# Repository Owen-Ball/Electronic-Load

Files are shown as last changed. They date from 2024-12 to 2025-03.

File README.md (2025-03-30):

# Overview
 A DIY electronic load capable of 
* CC, CR, CP, Battery (BT) Modes
* 30V, 50mA-7.5A, 120W
* 0-12V @ 3mV resolution, 0-40V @ 10mV resolution
* 0-1A @ 300uA resolution, 0-10A @ 2.5mA resolution

The design uses a custom PCB featuring an ESP32S3 Feather microcontroller. 4 power FETs dissipate the power via a CPU heatsink and current is measured using a bank of power resistors. With proper calibration, measurements/setpoints are within 1% across the entire operational range. 

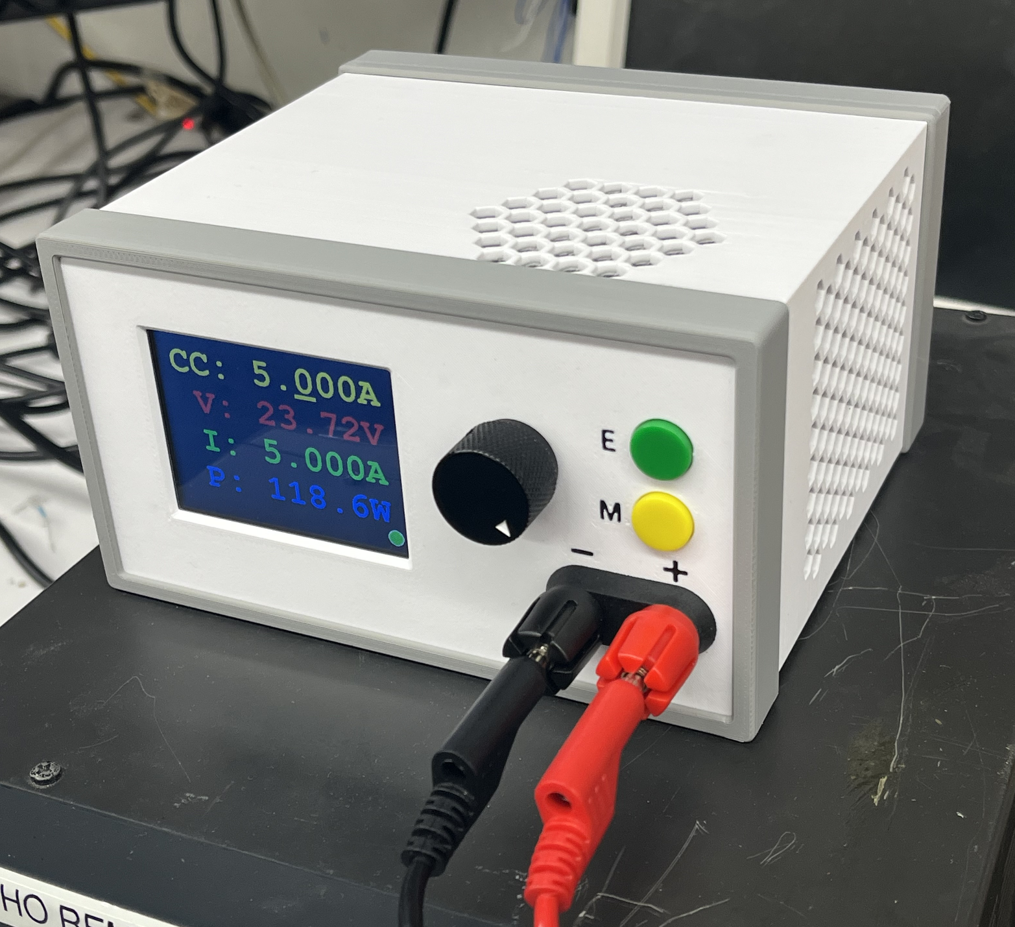
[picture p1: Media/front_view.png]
Front View

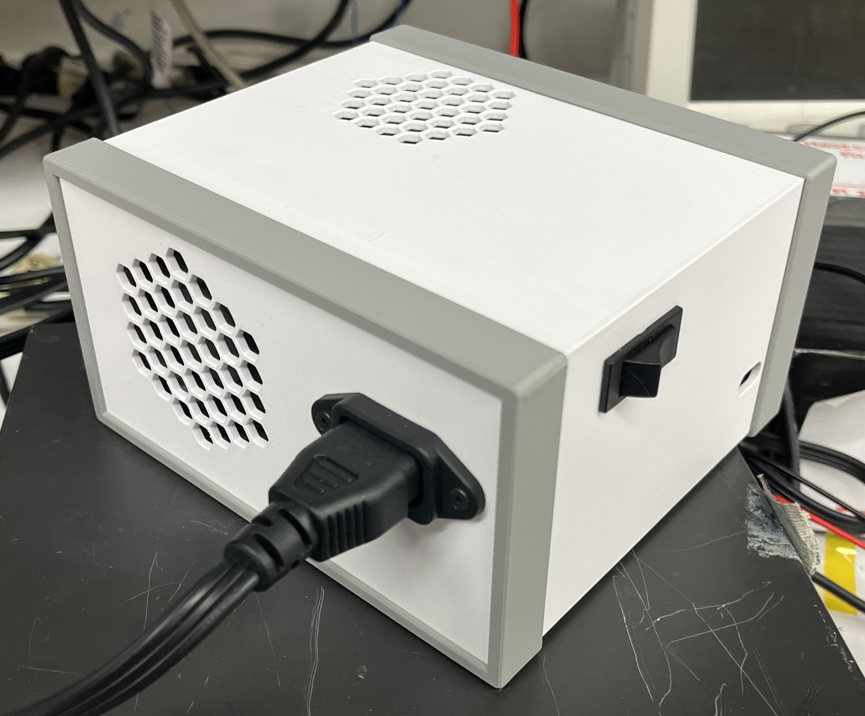
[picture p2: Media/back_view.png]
Back View


# To Do Feature List
* Check that the FET that burned is properly secured to heatsink
* CV mode? Not really sure for what application though

# Device Usage
This section provides a brief overview of device operation, including
* An overview of the UI elements
* Using the UI to operate the device
* Some potential pitfalls and things to look out for using the device
* Proper power connections and USB-C connections
## UI Overview
There are 5 "screens" on the UI, corresponding to the 4 operating modes of the device and a calibration screen. These are cycled through with the "mode" (M) button. The current mode is indicated in the top left. On each screen, the output can be enabled with the "enable" (E) button.

On each screen, the top-most value is the setpoint for the mode. This value is changed via the encoder. The 3 values below this are the measured values, which consist of the voltage, current, and either the power or discharged mAh in the case of battery mode. The temperature is also displayed at the bottom, along with any error messages. The output state is indicated by a red (off) or green (on) circle in the bottom right.

## Firmware Operation
On each screen, the rotary encoder can be used to change the setpoint within the system bounds. The place value being edited can be changed by clicking the encoder to cycle through place values, or by pressing down the encoder and turning it.

Once on the desired mode and with the correct setpoint, the enable button can be used to toggle the system output. The output indicator will turn green. If the output turns off unexpectedly, an error/warning message should be displayed indicating the reason, with most of these going away next time the enable button is pressed.

All modes operate in general by very roughly setting a current, maybe with 10-25% accuracy. The actual current is monitored and used to adjust the setpoint. This is done with an integral controller, which requires some sanity checking to ensure system safety. If there is no source connected (or it is underpowered), the system will detect this and shut off the output. More specifically, if the set current and measured current are not within a certain tolerance of each other for a set amount of time, the output is disabled.

Other reasons for system shutoff are voltage or temperature limits being exceeded. In CR or CP modes, since the current is automatically calculated the output will be shut off if the system tries to set the current or power above the system limit.

In rare circumstances the system can oscillate. This will occur in the presence of a slow responding source in series (ie an incandescent bulb) or through interactions with the feedback system of a power supply. There is no protection against this, so turn the system off if observed.

## Hardware Operation
While the system has some reverse polarity protection, it is highly recommended that this is not relied on. As such, make sure to connect the higher potential of the source to the +/red terminal and the lower to the -/black terminal. While the system should draw no current while powered off, I recommend having the system powered before connecting a source.

When connecting to the Feather using a USB-C cable, a cable with the 5V line cut is recommended. The system has diodes on the 5V lines so there are no shorting risks, but for some reason the system measurements differ by around 1% depending on whether the system receives USB power or not. Thus for calibration using the serial monitor, a cable with no power is essential. 

The system can be put into bootloader mode by pressing down the encoder while turning on the system (assuming you bridge the encoder pin and bootloader testpad on the feather together).

Additionally, please use caution when operating the device, as mains 120V power is used. There are potential areas of risk, including power supply failure and improper crimping for the live wires.

# Hardware

## Microcontroller

The microcontroller used is the ESP32S3 feather. This was done with the intention of adding WiFi support to the device for the monitoring and setting of parameters. However, the ESP32S3 has issues using both the ADC and WiFi at the same time, so this feature is on hold. Additionally, I did not have any significant use cases for the WiFi anyways. If not implementing WiFi functionality, the ESP32 is a poor choice due to the extremely non-linear ADCs that mandate extensive calibration.

## Power Components:
The bulk of the power is burned using 4 [IRFB7545PBF](https://www.digikey.com/en/products/detail/infineon-technologies/IRFB7545PBF/4772483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) NCH MOSFETs (TO-220). The FETs are mounted to a [CPU heatsink](https://www.amazon.com/dp/B00006B8EX?ref=ppx_yo2ov_dt_b_fed_asin_title&th=1) to thermally couple them and provide power dissipation. Current measurements are done using the voltage across banks of [RSMF2JT4R70](https://www.digikey.com/en/products/detail/stackpole-electronics-inc/RSMF2JT4R70/2021732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) 4.7 Ohm resistors. Each FET is in series with a bank of 4 of these resistors in parallel. The resistors are cooled via a fan mounted to the system case.

A 10A fuse is placed in series with the + input to the system. Some degree of reverse polarity protection is present in the form of a reverse biased diode across the input ports after the fuse. This ideally will limit reverse voltages to less than 1V but has not been tested.

## Sensing
All sensing is done via the ADCs on the ESP32S3. Accurary could be improved by purchasing more accurate standalone ICs for voltage and current measurements however. 

Voltage sensing has two ranges, 0-12V and 0-<span style="color:red"> 40V (need to check)</span>. Thus for a 12-bit ADC, resolution is around 3mV/step and 10mV/step. Both sensors operate using a simple voltage divider to divide down the max voltage to the maximum ADC input of ~3.2V. 7.5V zener diodes are used to clamp the voltage input to the ADCs to ~3.75V. 7.5V zeners are used since lower voltage zeners feature a less sharp turn on that would increase leakage and worsen the voltage clamping. One note is the pin used for the high voltage range on the ESP32S3 feather has an SMD LED attached to it (not sure why they put the on-board LED on an analog in pin...). For high voltage inputs, this drives the LED, which is not ideal and causes non-linearity in the measurement that needs to be compensated for. The LED could of course be removed, but I did not do this.

Current sensing is done with two ranges as well, although there are some major design oversights. The original intention was to have two operating modes, one where all 4 FETs were running and one were only a single one was active. This would enable higher precision for low current measurements. Thus 3 of the 4 FETs are controlled by 1 DAC and the final one is controlled by a separate DAC. 

The high sensitivity current sensor amplies the voltage across the power resistors by a factor of 10. Thus for 16 shunt resistors, this range maxes out around 1.1A. The design oversight is that this sensor is only hooked up to the independently controlled FET path, so in high current mode, this sensor is not truly measuring the current, it is "guessing" based on a measurement of 1/4 of the current.

The low sensitivity (higher range) current sensor uses resistors to average the voltages across the 4 shunts. This means it works properly in high current mode, but not in low, since this setup will not work when only the one FET is active. This mode peaks at around <span style="color:red"> 10A (need to check)</span>.

As a summary of the design oversights, the only fully functioning current sensing modes would be high current mode + low sensitivity sensor and low current mode, high sensitivity sensor. After discovering this issue, I cut support for low current mode entirely since I currently do not have a use case for the latter mode (would be 0-250mA), although this may be added in the future. I did decide to use the high sensitivity current sensor is used in high current mode despite only directly measuring 1/4 of the current.

# Firmware Details
More details regarding the firmware implementation can be found in the firmware-specific readme
[here](./Firmware/Firmware_ReadMe.md)

This includes:
* Error codes
* Feedback loops
* System FSM
* Calibration
* Setup

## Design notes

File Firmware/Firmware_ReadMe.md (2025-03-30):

# Error/Warning Codes
The system features a handful of warnings and errors that will be displayed on the screen. These are as follows:
* No message (NO_ERROR): No error present
* "I Sense Fail" (C_SENSE_ERROR): Discrepancy between low and high current sensors. Disables device, cannot be overwritten
* "Over Current" (OVER_C_ERROR): Current went over system limit
* "Over Voltage" (OVER_V_ERROR): Voltage went over system limit
* "Over Power" (OVER_P_ERROR): Power went over system limit
* "Over Temp" (OVER_T_ERROR): Heatsink temp went over system limit
* "I_Set!=I_Meas" (MISMATCH_ERROR): Set current is not being achieved within required margin of error

When triggered, a warning/error will turn off the output. Of these, all but C_SENSE_ERROR can be reset by simply re-enabling the output. 
C_SENSE_ERROR could indicate a failure of one of the power MOSFETs and can only be disabled via a power cycle. You should proceed with 
caution by testing the device at ~1A using a current limited supply.

# Library & Board Version Info
* Espressif Systems esp32: v2.0.14
    * Board: Adafruit Feather ESP32-S3 2MB PSRAM
    * Add https://raw.githubusercontent.com/espressif/arduino-esp32/gh-pages/package_esp32_index.json in _Additional Boards Manager_
* Adafruit BusIO: v1.16.2
* Adafruit_MCP4725: v2.0.2
* ESP32_FastPWM: v1.1.0
* ESP32Encoder: v0.11.6
* [FlickerFreePrint](https://github.com/KrisKasprzak/FlickerFreePrint) 
* TFT_eSPI: v2.5.43
    * Need to overwrite _Arduino\libraries\TFT_eSPI\User_Setup.h_ with the following: [User_Setup.h](User_Setup.h)

# Modes of Operation
All modes operate around setting a current on the device. Depending on the mode, this may be a constant current or it can be a function of voltage.

## Constant Current
Constant current mode directly sets a current output and attempts to keep it stable. 
The DACs in the device are only loosely calibrated, so when CC mode is started, 
the DACs are set roughly to the required voltage. The actual current is monitored 
and an integral controller is used to update the set DAC value until the measured 
current matches the user setpoint. This allows the device to maintain a constant 
current no matter what the applied voltage, temperature of FETs, etc is. Sanity 
checks must be performed to ensure the DAC setpoint and the measured current are
within some tolerance of each other to prevent runaway of the integral controller.

## Constant Power
Under the hood, constant power method uses the feedback loop from constant current mode. 
The only change is that in constant power mode, the target current value is calculated by
dividing the set power by the measured voltage. Because the device does not have sense wires,
the voltage drops of wires and connectors will impact the measured voltage. The result of this is
that slightly more power will be drawn from the connected supply than measured by the device.

## Constant Resistance
This mode also uses constant current mode, but the target current is set to the measured voltage divided
by the set resistance. Due to wire and connector drops, the actual current drawn will be slightly
lower than if the supply was connected to some ideal resistor of the set value.

## Battery Discharge Mode
In battery discharging mode, the device starts by pulling 5A from the connected supply. This
is achieved using the same constant current feedback loop as all other modes.
The measured voltage is compared to the user set end voltage. If the voltage drops below the end voltage
(some battery and E-load internal resistance is accounted for), the current setpoint will be 
dropped by a set value (currently 0.05A). This will occur until a minimum current is reached, at
which point the device will turn off. The battery voltage should now be quite close to the
set end voltage.

In battery discharge mode, the power reading is replaced by a mAh reading that indicates the total
number of mAh consumed from the battery. This value will be cleared when the mode is changed,
but will not change when you toggle the output on and off. When turned off and back on, the
current will reset to 5A

## Calibration Mode
This mode is used to account for resistive drops in the Eload and wires. This mode will set the current to 1A 
when the output is enabled. The resistance value shown can be changed until the voltage measured by the Eload 
matches with the voltage measured at the desired location with a kelvin connected voltmeter. The resistance value
set in this mode will be used in all other modes to update the measured voltage in accordance with the measured current.

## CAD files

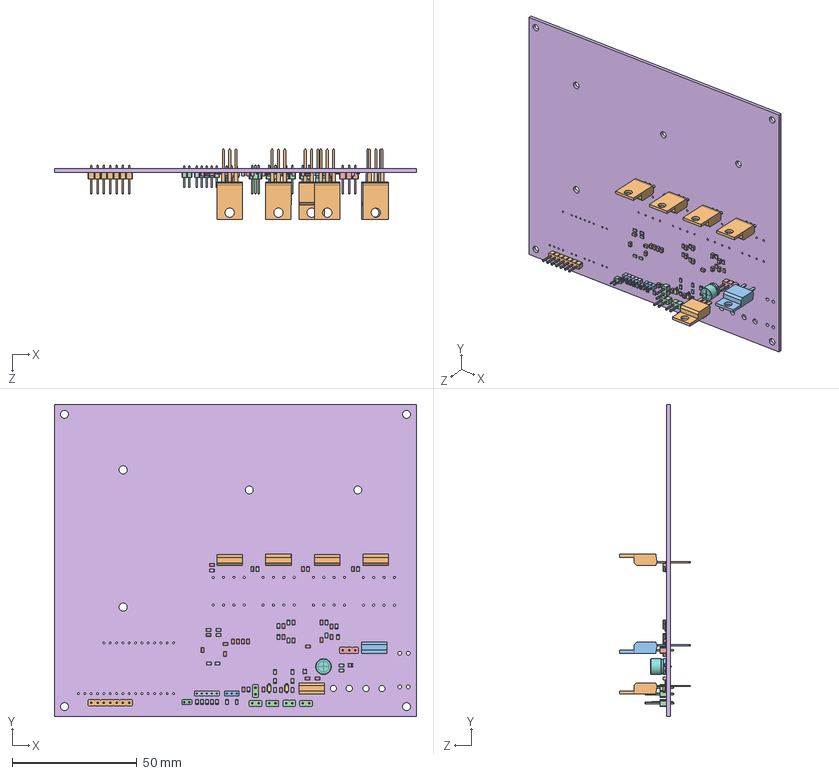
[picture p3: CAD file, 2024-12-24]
CAD/Board/Board.SLDASM
145.0 x 125.0 x 28.5 mm
Main PCB

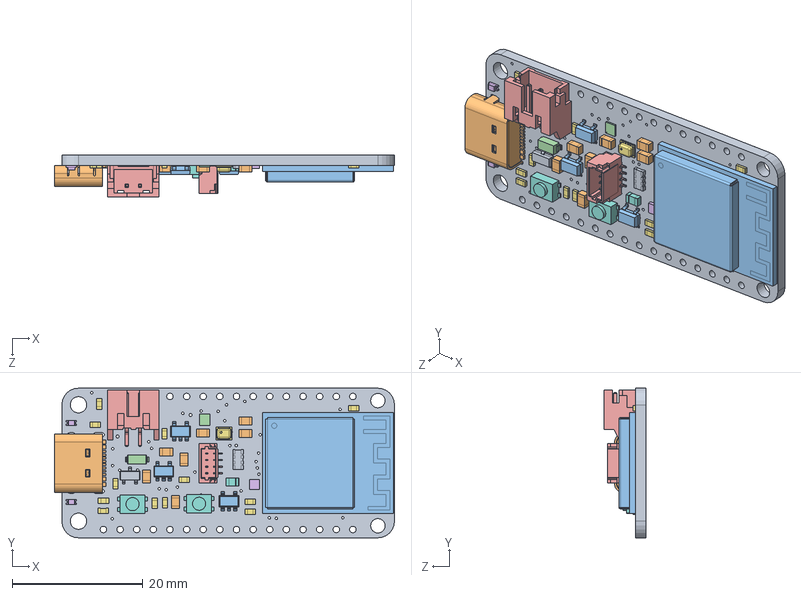
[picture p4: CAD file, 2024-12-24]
CAD/ESP32S3/5303 Feather ESP32-S3.SLDASM
51.9 x 22.9 x 6.37 mm
Board
10uF x 7
AP2112_RT9080-3.3 x 3
MBR540
JSTPH
RED x 2
1uF x 12
KMR2 x 2
DMG3415U
USB C
ESP32-S2-MODULE_MINI
LC709203F_MH
JST SH
WS2812B_SK6805_1515
BME280
10uF_1
10K

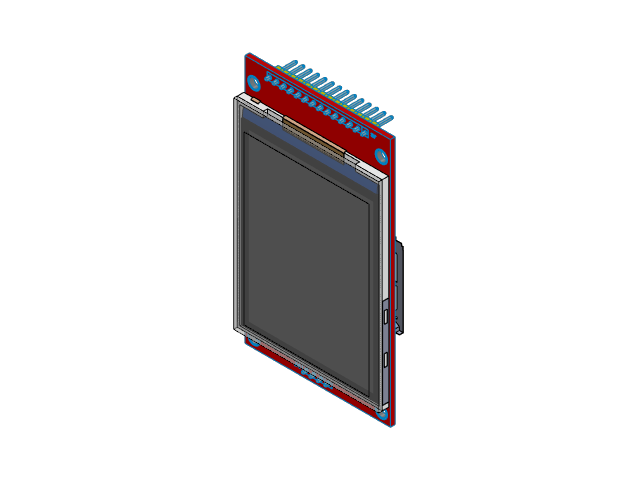
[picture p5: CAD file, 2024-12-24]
CAD/Screen/2.8 TFT Module.SLDASM
2.8 LCD TFT Module - Without Glass
0603 Resistor
0603 Capacitor x 2
SOT23-3 x 2
2.8in TFT(Without Glass)- Tucked Cable
front_glass

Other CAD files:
CAD/Board/Main PCB.SLDPRT
CAD/Board/TO-220-2_Vertical.SLDASM
CAD/Main PCB.SLDPRT
CAD/Board/PinHeader_1x02_P2.00mm_Vertical.SLDASM
CAD/Board/D_SOD-123.SLDASM
CAD/Board/D_0805_2012Metric.SLDASM
CAD/Board/TO-220-3_Vertical.SLDASM
CAD/Board/PinHeader_1x07_P2.54mm_Vertical.SLDASM
CAD/Board/R_0805_2012Metric.SLDASM
CAD/Board/PinHeader_1x03_P2.00mm_Vertical.SLDASM
CAD/Board/PinHeader_1x03_P2.54mm_Vertical.SLDASM
CAD/Board/PinHeader_1x02_P2.54mm_Vertical.SLDASM
CAD/Board/CP_Radial_D6.3mm_P2.50mm.SLDASM
CAD/Board/PinHeader_1x05_P2.00mm_Vertical.SLDASM
CAD/ESP32-S2-MODULE_MINI.SLDPRT
CAD/0603 Capacitor.SLDPRT
CAD/0603 Resistor.SLDPRT
CAD/10K.SLDPRT
CAD/10uF.SLDPRT
CAD/10uF_1.SLDPRT
CAD/1uF.SLDPRT
CAD/2.8 LCD TFT Module - Without Glass.SLDPRT
CAD/2.8in TFT(Without Glass)- Tucked Cable.SLDPRT
CAD/5035000993.SLDPRT
CAD/AP2112_RT9080-3.3.SLDPRT
CAD/BME280.SLDPRT
CAD/BindingPost.SLDPRT
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

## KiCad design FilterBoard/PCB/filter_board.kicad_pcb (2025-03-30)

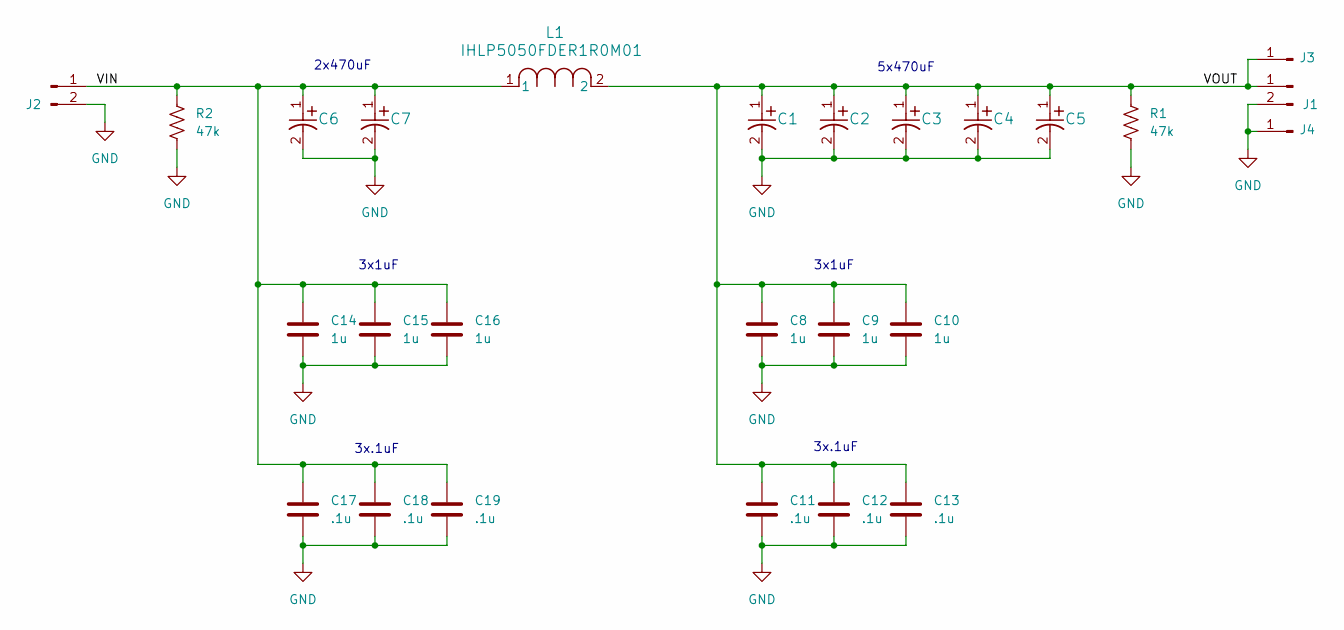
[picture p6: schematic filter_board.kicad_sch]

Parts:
C1, C2, C3, C4, C5, C6, C7: EMHB630ARA471MMH0S
C8, C9, C10, C14, C15, C16: 1u; C_0805_2012Metric
C11, C12, C13, C17, C18, C19: .1u; C_0805_2012Metric
J1: Banana_Terminals
J2: Banana Terminals; Banana_Terminals
J3, J4: Conn_01x01_Pin; Wire_Pad
L1: IHLP5050FDER1R0M01; IND_IHLP-5050FD-01_VIS
R1, R2: 47k; R_0805_2012Metric

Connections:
/VIN: C6.1, C7.1, C14.1, C15.1, C16.1, C17.1, C18.1, C19.1, J2.1, L1.1, R2.1
/VOUT: C1.1, C2.1, C3.1, C4.1, C5.1, C8.1, C9.1, C10.1, C11.1, C12.1, C13.1, J1.1, J3.1, L1.2, R1.1
GND: C1.2, C2.2, C3.2, C4.2, C5.2, C6.2, C7.2, C8.2, C9.2, C10.2, C11.2, C12.2, C13.2, C14.2, C15.2, C16.2, C17.2, C18.2, C19.2, J1.2, J2.2, J4.1, R1.2, R2.2

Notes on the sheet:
2x470uF
3x.1uF
5x470uF
3x1uF

Board: 2 copper layers, 26 parts (0 on the bottom side), 3 nets, no tracks yet.

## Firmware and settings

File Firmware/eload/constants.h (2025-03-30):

#ifndef _CONSTANTS_
#define _CONSTANTS_

enum OUT_STATE {OUT_ON, OUT_OFF};
enum MODE {CC, CV, CP, CR, BAT, R_CAL};
enum CURRENT_LIMIT {CURR_LOW, CURR_HIGH};

//NO_ERROR: No error present. Set to this value when output enabled
//C_SENSE_ERROR: Discrepancy between low and high current sensors
//               Disables device, cannot be overwritten
//OVER_C_ERROR: Current went over system limit
//OVER_V_ERROR: Voltage went over system limit
//OVER_P_ERROR: Power went over system limit
//OVER_T_ERROR: Heatsink temp went over system limit
//MISMATCH_ERROR: Set current is not being achieved within required margin of error
enum ERROR_CODE {NO_ERROR, C_SENSE_ERROR, OVER_C_ERROR, OVER_V_ERROR, OVER_P_ERROR, OVER_T_ERROR, MISMATCH_ERROR};

//Setpoint Bounds
#define MAX_CURRENT_LOW_SET   1.50
#define MAX_CURRENT_HIGH_SET  7.50
#define MAX_VOLTAGE_SET       30.00
#define MIN_RESISTANCE_SET    0.50
#define MAX_RESISTANCE_SET    500.00
#define MAX_POWER_SET         120.00
#define MAX_CAL_SET           0.5

//Configure default setpoint values
#define DEFAULT_CC            1.00
#define DEFAULT_CV            5.00
#define DEFAULT_CP            10.00
#define DEFAULT_CR            10.00
#define DEFAULT_BAT           15.30
#define DEFAULT_RCAL          0.0

//The current that will be injected during calibration
#define I_CAL                 1.0

//System Limits
#define CURRENT_LOW_LIMIT     2.00
#define CURRENT_HIGH_LIMIT    7.7
#define VOLTAGE_LIMIT         33.00
#define POWER_LIMIT           125.0
#define TEMP_LIMIT            60.0



//Pins
#define FAN_PIN               11
#define PWM_RES               10
#define PWM_FREQ              20000
#define PWM_CHANNEL           0

#define ENABLE_BUTTON_PIN     38
#define CURRENT_BUTTON_PIN    14
#define MODE_BUTTON_PIN       39
#define ENCODER_BUTTON_PIN    16
#define ENCODER_A             3
#define ENCODER_B             4

#define VSENSE_LARGE          13
#define VSENSE_SMALL          12
#define CURRSENSE_LARGE       6
#define CURRSENSE_SMALL       5
#define THERMISTOR_PIN        8

#define DAC_SDA               10
#define DAC_SCL               9

//debounce time for all I/O buttons
#define DEBOUNCE_TIME_MS      50
//Takes N digital readings of each button, all must agree for output state to toggle
//This was implemented to solve an infrequent issue where the current limit would randomly update due to
//digitalRead of the button returning the wrong value
#define BUTTON_AVG_COUNT      10




//Below this voltage the low voltage sensor will be used
#define V_THRESH_LOW          11.0
//Above this voltage the high voltage sensor will be used
//Between them the previous sensor is used
#define V_THRESH_HIGH         12.0

//On the high current setting, below this current the low current sensor is used
#define C_THRESH_LOW          0.7
//On the high current setting, above this current, the high current sensor is used
#define C_THRESH_HIGH         0.8

//defines how long the current can be outside of 25% of the setpoint before being cut (ms)
#define OUT_KILL_TIME_LIMIT   500




//Vertical spacing between lines
#define LETTER_HEIGHT         50
//defines the x coordinate of the left of the numbers
#define LETTER_X              45
//defines the y coordiante of the top of the numbers
#define LETTER_Y              50

//time in ms between screen updates
#define SCREEN_REFRESH        75

#define DEBUG_LEN             21



//Defines the number of samples taken for analog input readings
#define SAMPLE_COUNT          200
//If the large current reads this much above the small current sensor, turn off the device
#define SAFETY_OFFSET         0.25
//Triggering of the safety shutoff requires this many invalid readings in a row
#define SAFETY_COUNT          3
//sets the IIR filter used on values before displaying them. 
//Only impacts the displayed values, not the values used in control loops and such
//0 = no filter, -> 1 = high filtering
#define MEASUREMENT_FILTER    .75
//Will skip filtering and directly set the measured value if the filtered value has a percent error
//greater than the below value. Makes output responsive to large steps
#define FILTER_THRESHOLD      .02




//sets the gain of the integral controller for current setpoint
//1 or above likely to cause oscillations
#define CURRENT_SET_GAIN      .8

//Filters how fast the set current can change for CR, CP, CV
#define CURRENT_SET_FILTER    .75



//time in ms between current decreases in battery discharge mode
#define BAT_UPDATE_TIME       100
//Value of current steps in battery discharge mode
#define BAT_CURRENT_STEP      .05
//Speeds up discharging process by allowing measured voltage to drop below desired end voltage when
//at high currents, since resistive losses result in voltage drop
//Must be below actual resistance to avoid over discharging
#define BAT_RESISTANCE        0.02
//Cut off current for battery discharging
#define BAT_END_CURRENT       0.2

#endif // _CONSTANTS_

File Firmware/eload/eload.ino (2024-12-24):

#include "Arduino.h"
#include <cstdint>
#include "drawing.h"
#include "IO.h"
#include "helpers.h"
#include "FSM.h"
#include "debug_utils.h"

long prevtime;

void setup() {
  
  pinMode(VSENSE_LARGE, INPUT);
  pinMode(VSENSE_SMALL, INPUT);
  pinMode(CURRSENSE_LARGE, INPUT);
  pinMode(CURRSENSE_SMALL, INPUT);
  pinMode(THERMISTOR_PIN, INPUT);
  
  encoder.attachFullQuad (ENCODER_A, ENCODER_B);
  
  Wire.begin(DAC_SDA, DAC_SCL);
  dac_low.begin(0x60, &Wire);
  dac_high.begin(0x61, &Wire);
  dac_low.setVoltage(0, false);
  dac_high.setVoltage(0, false);

  Serial.begin(115200);
  
  tft.init();
  tft.setRotation(1);
  tft.fillScreen(TFT_BLACK);
  tft.setTextSize(1);
  tft.setTextColor(TFT_YELLOW, TFT_BLACK);
  tft.setFreeFont(&FreeMonoBold24pt7b);

  encoder_button.begin();
  enable_button.begin();
  mode_button.begin();
  current_button.begin();
  coolingFan = new ESP32_FAST_PWM(FAN_PIN, PWM_FREQ, 0.0f, PWM_CHANNEL, PWM_RES);

  initSystem();

  prevtime = millis();
}

void loop() {
  
  drawAll();
  updateSystem();
  
  DEBUG_PRINTLN(millis() - prevtime);
  DEBUG_PRINTLN("Error: " + String(ERRORS));
  
  prevtime = millis();

  //float small = analogReadAverage(CURRSENSE_SMALL, 1000);
  //float large = analogReadAverage(CURRSENSE_LARGE, 1000);
  //DEBUG_PRINTLN(String(small, 2) + " " + String(large, 2));
  //if (mode_button.pressed()) i+=100;
  //dac_low.setVoltage(i, false);
  //dac_high.setVoltage(0, false);
}

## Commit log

2024-06-16 Renamed main arduino file
2024-06-17 Added CR and CP functionality
    Added constant resistance and power modes. Need to fix the setpoint being kept constant between modes and need to add protection to shut the output off if the desired setpoint cannot be achieved.
    [IO.cpp, constants.h, eload.ino]
2024-06-28 Sped up main loop, added filtering to display measurements, parametrized text location
2024-06-28 Fixed some potential div by 0 issues and commented constants.h
    [constants.h]
2024-06-29 Screen refresh rate, placeholder for CV
    Added a screen refresh rate limit so the main loop can run fast while maintaining a reasonable refresh rate of values
    Added a placeholder for CV since the output would not shut off when switching to CV while output was on
2024-06-29 Added constant for CR, CP, CV filter
2024-07-21 Beginning implementation of battery discharge mode
2024-07-25 Initial implementation of battery discharge mode
2024-07-25 Debug function for printing values without USB
2024-12-14 Enforce system limits, new fan curves
    Shut down system when max power, current, or voltage exceeded (although doesn't really help in the case of voltage)
    Updated fan profile to also factor in current, not just heat sink temperature
    Remapped I/O buttons
    [IO.cpp, constants.h, eload.ino]
2024-12-16 Lowered power limit, started readme
    Attempted very brief operation at 180W, instantly smoked a FET. Lowered power limit from 135W to 120W as a precaution, despite no issues being observed at 135W.
    Also lowered max current to be same as current setpoint, I don't really want the system going above 7.5A
    Started README file
    [constants.h]
2024-12-16 Untested safety code + error status
    Implemented check of agreement between the two current sensors.
    Also began implementation of error flags, although they currently cannot be accessed (will display error codes on screen in future update)
    [IO.cpp, constants.h]
2024-12-17 Moved Button Library, work on error msg
    Added untested error printing code
    Also moved Button library from my libraries folder to the repository since it was modified slightly
    [IO.cpp, constants.h]
2024-12-24 Print temperature and bypass CV mode
    Print temperature to screen, added overtemp error, and bypass CV mode when using the Mode button
    [IO.cpp, constants.h, eload.ino]
2024-12-24 Added CAD folder
    [0603 Capacitor.SLDPRT, 0603 Resistor.SLDPRT, 10K.SLDPRT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]
2024-12-24 Readme updates
    [back_panel.STL, back_trim.STL, bacl_trim.SLDPRT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]
2025-01-04 Updated firmware setup info
    tried to compile on new system and realized some issues with the Arduino setup information
    [User_Setup.h]
2025-01-26 Adding filter board KiCAD files
    external filter board to reduce the large ripple currents the Eload produces
    [filter_board.kicad_pcb, filter_board.kicad_sch]
2025-02-01 Filter board layout tweaks
    [filter_board-B_Cu.gbr, filter_board-B_Mask.gbr, filter_board-B_Paste.gbr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]
2025-03-30 Added cal mode to eload + work on filter board
    Added a cal mode to correct for resistive drops on wires. Also some updates to the filter board PCB
    [filter_board-F_Cu.dxf, filter_board.kicad_pcb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]
2025-04-25 fixed internal R calibration
    Internal R calibration was only applied to displayed values, it wasn't used for setpoint calcs
